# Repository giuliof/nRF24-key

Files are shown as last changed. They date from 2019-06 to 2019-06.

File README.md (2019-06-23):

# nRF key

Interface for Nordic nRF24L01 wireless modules.

## Project structure

In this repository you can find:
```
nRF-key
 |__ schematics --> KiCAD schematic
 |__ code       --> source code for ATtiny2313 microcontroller
```

## BOM

|Designator | Description | MPN |
|---|---|---|
|C2 C7 C8 C10  | capacitor 100n 0805 | 0805F104M500NT |
|C9 | capacitor tantalum 10u | TAJA106K016RNJ |
|C5 C6 | capacitor 22p 0805 | 0805N220J500CT |
|D1 D2 D3 | red led 0805 | QBLP631-R |
|R1 R5 | resistor 10k 0805 | RC0805JR-0710KL |
|R2 R3 R4 | Resistor 330 0805 | 0805W8J0331T5E |
|U2 | microcontroller ATtiny2313 | ATTINY2313A-SU |
|U1 | usb ttl uart ch340c | CH340C |
|U3 | LDO voltage regulator 3v3  | MCP1700T-3302E/TT |
|Y1 | crystal 8M | 1C208000BC0R |

## Code features

Communication with nRF key is via 9600baud 8N1 serial port. Data received from another module is printed. Data to send is packaged in a 32byte maximum structure and must be followed by CR. Bytes over 32 (except for CR) will be ignored.
This is not a transparent bridge, but can be easily implemented.

nRF24L01 registers (i.e. tx/rx addresses) can be reprogrammed pressing programming button (i.e. holding low BTN/PD4 line) while inserting key. Programming mode is selected (both TX_LED and RX_LED will turn on), next 32byte will be stored in settings EEPROM. Data is structured as following:

| Byte n. | Function |  nRF reg. |
|---|---|---|
| 0 |Configure register | 0 |
| 1 |Enable automatic answer function | 1 |
| 2 |Enable receive address | 2 |
| 3 |Setup address width | 3 |
| 4 |Automatic retransmission | 4 |
| 5 |Set channel frequency | 5 |
| 6 |Set transmission rate, LNA gain, transmit power  | 6 |
| 7&div;11|RX address for data channel 0 | 10 |
|12&div;16|RX address for data channel 1 | 11 |
| 17 |RX address for data channel 2 | 12 |
| 18 |RX address for data channel 3 | 13 |
| 19 |RX address for data channel 4 | 14 |
| 20 |RX address for data channel 5 | 15 |
|21&div;25|TX address | 16 |
| 26 |RX data for channel 0 | 17 |
| 27 |RX data for channel 1 | 18 |
| 28 |RX data for channel 2 | 19 |
| 29 |RX data for channel 3 | 20 |
| 30 |RX data for channel 4 | 21 |
| 31 |RX data for channel 5 | 22 |

## How To

1. Make the PCB and solde it (I have a protoboard version too);
2. Obtain an AVR programmer (usbasp or Arduino as ISP)
3. Compile the code:
 * install `gcc-avr` `avr-libc` `avrdude`;
 * move in code directory;
 * type `make`;
 * check in Makefile if the programmer is correct;
 * type `make eeprom` then `make flash`.

## Authors

* **Giulio Fieramosca** - [giuliof](https://github.com/giuliof)

## License

This project is released under the MIT License - see the [LICENSE.md](LICENSE.md) file for details

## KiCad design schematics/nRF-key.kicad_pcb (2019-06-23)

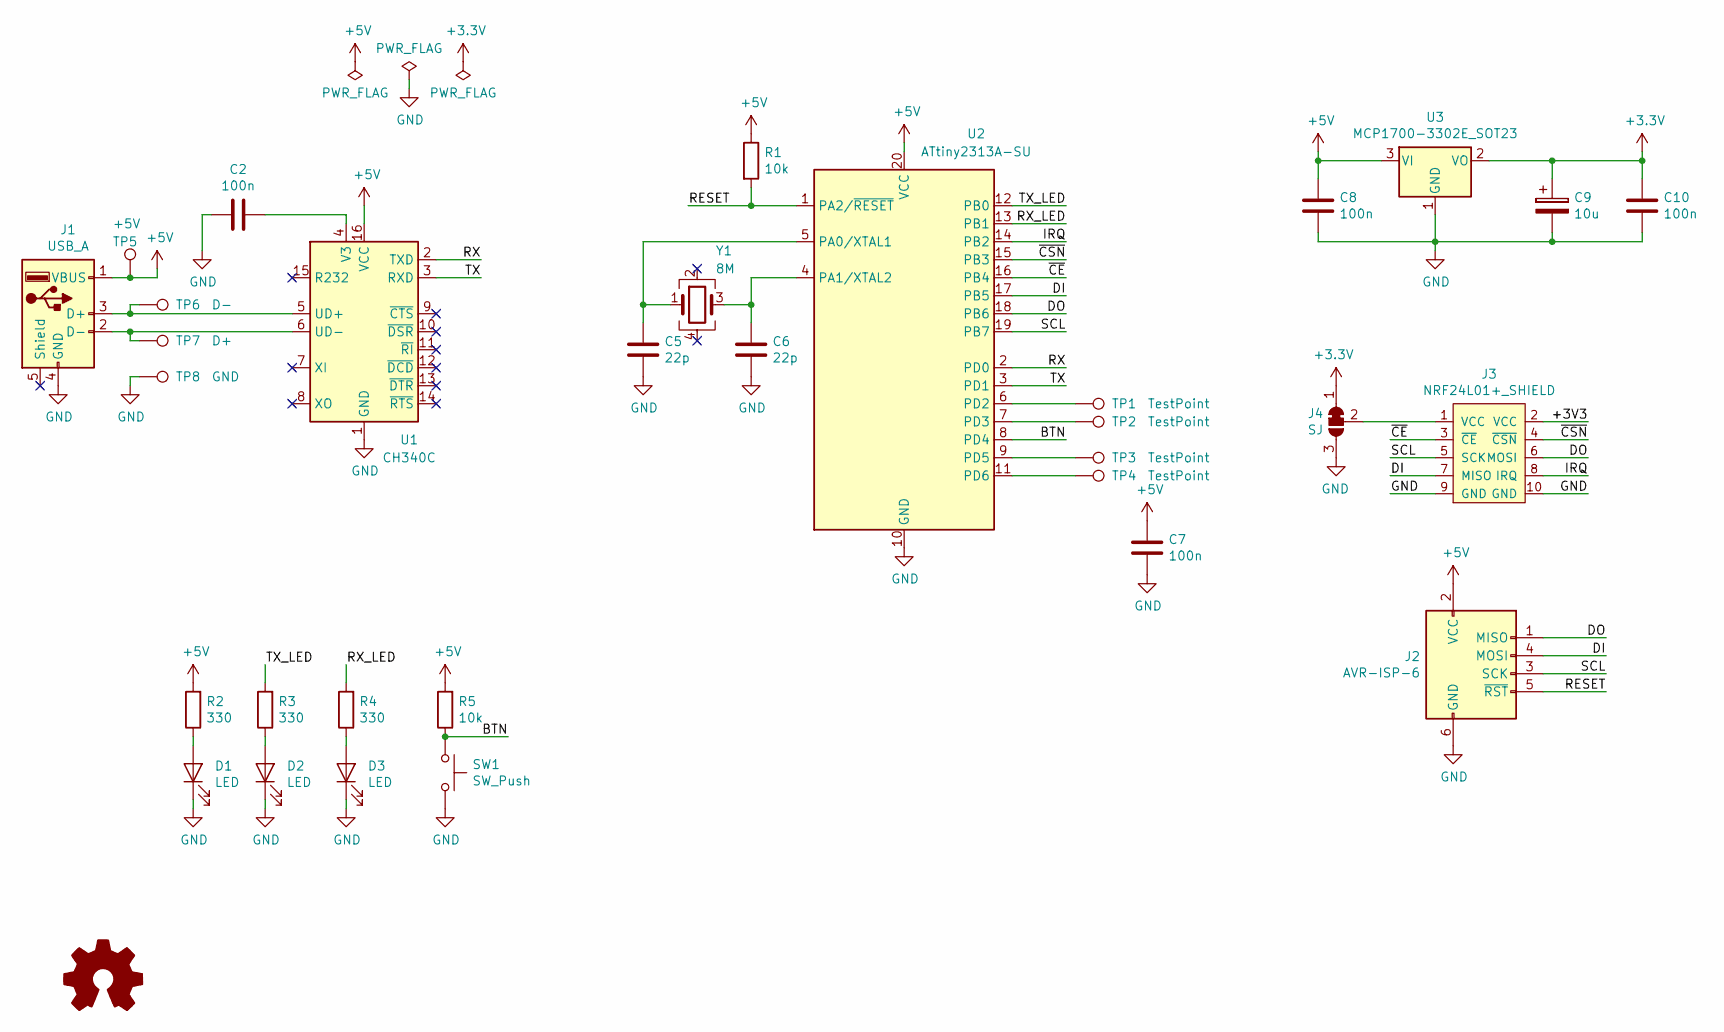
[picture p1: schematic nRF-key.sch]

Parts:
C2, C7, C8, C10: 100n; C_0805_2012Metric; Part no 0805F104M500NT
C5, C6: 22p; C_0805_2012Metric; Part no 0805N220J500CT
C9: 10u; CP_EIA-3216-12_Kemet-S; Part no TAJA106K016RNJ
D1, D2, D3: LED; LED_0805_2012Metric; Part no QBLP631-R
J1: USB_A; usb-PCB
J2: AVR-ISP-6; PogoPins-2x03-ICSP
J3: NRF24L01+_SHIELD; nRF24-2x05_P2.54mm
J4: SJ; SolderJumper-3_P1.3mm_Open_RoundedPad1.0x1.5mm
LOGO1: Logo_Open_Hardware_Small; oshw-logo-10mm
R1, R5: 10k; R_0805_2012Metric; Part no RC0805JR-0710KL
R2, R3, R4: 330; R_0805_2012Metric; Part no 0805W8J0331T5E
SW1: SW_Push; _PTS525SK15-SMT-Pushbutton
TP1, TP2, TP3, TP4: TestPoint; TestPoint_THTPad_D1.0mm_Drill0.5mm
TP5: +5V; TestPoint_THTPad_D1.0mm_Drill0.5mm
TP6: D-; TestPoint_THTPad_D1.0mm_Drill0.5mm
TP7: D+; TestPoint_THTPad_D1.0mm_Drill0.5mm
TP8: GND; TestPoint_THTPad_D1.0mm_Drill0.5mm
U1: CH340C; SOIC-16_3.9x9.9mm_P1.27mm; Part no CH340C
U2: ATtiny2313A-SU; SOIC-20W_7.5x12.8mm_P1.27mm; Part no ATTINY2313A-SU
U3: MCP1700-3302E_SOT23; SOT-23; Part no MCP1700T-3302E/TT
Y1: 8M; Crystal_SMD_3225-4Pin_3.2x2.5mm; Part no 1C208000BC0R

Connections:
+5V: C7.1, C8.1, J1.1 (VBUS), J2.2 (VCC), R1.1, R2.2, R5.2, TP5.1, U1.16 (VCC), U2.20 (VCC), U3.3 (VI)
/BTN: R5.1, SW1.1, U2.8 (PD4)
/DI: J2.4 (MOSI), J3.7 (MISO), U2.17 (PB5)
/DO: J2.1 (MISO), J3.6 (MOSI), U2.18 (PB6)
/IRQ: J3.8 (IRQ), U2.14 (PB2)
/RESET: J2.5 (~RST), R1.2, U2.1 (PA2/~RESET)
/RX: U1.2 (TXD), U2.2 (PD0)
/RX_LED: R4.2, U2.13 (PB1)
/SCL: J2.3 (SCK), J3.5 (SCK), U2.19 (PB7)
/TX: U1.3 (RXD), U2.3 (PD1)
/TX_LED: R3.2, U2.12 (PB0)
/~CE~: J3.3 (~CE~), U2.16 (PB4)
/~CSN~: J3.4 (~CSN~), U2.15 (PB3)
GND: C2.2, C5.2, C6.2, C7.2, C8.2, C9.2, C10.2, D1.1 (K), D2.1 (K), D3.1 (K), J1.4 (GND), J2.6 (GND), J3.9 (GND), J3.10 (GND), J4.3 (B), SW1.2, TP8.1, U1.1 (GND), U2.10 (GND), U3.1 (GND)
unnamed: C2.1, U1.4 (V3)
unnamed: C5.1, U2.5 (PA0/XTAL1), Y1.1
unnamed: C6.1, U2.4 (PA1/XTAL2), Y1.3
unnamed: D1.2 (A), R2.1
unnamed: D2.2 (A), R3.1
unnamed: D3.2 (A), R4.1
unnamed: J1.2 (D-), TP7.1, U1.6 (UD-)
unnamed: J1.3 (D+), TP6.1, U1.5 (UD+)
unnamed: J3.1 (VCC), J4.2 (C)
unnamed: TP1.1, U2.6 (PD2)
unnamed: TP2.1, U2.7 (PD3)
unnamed: TP3.1, U2.9 (PD5)
unnamed: TP4.1, U2.11 (PD6)

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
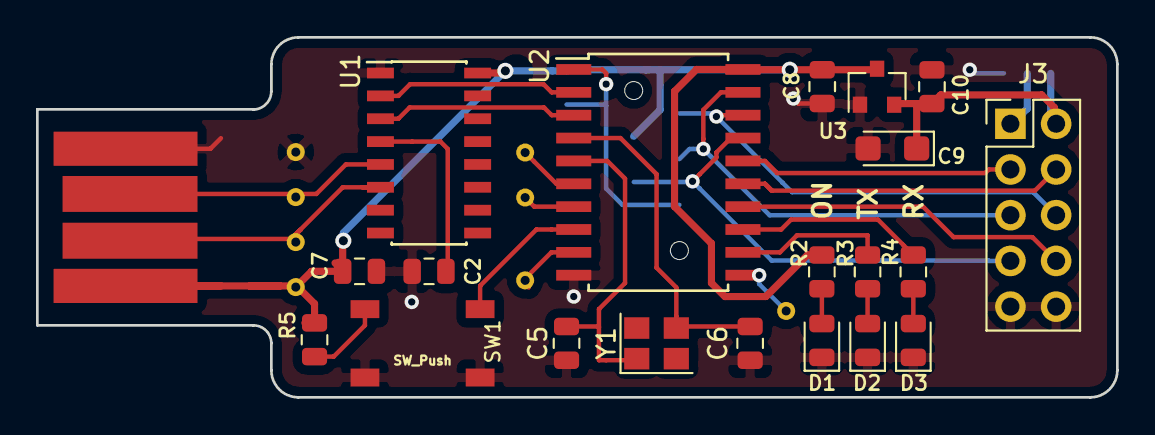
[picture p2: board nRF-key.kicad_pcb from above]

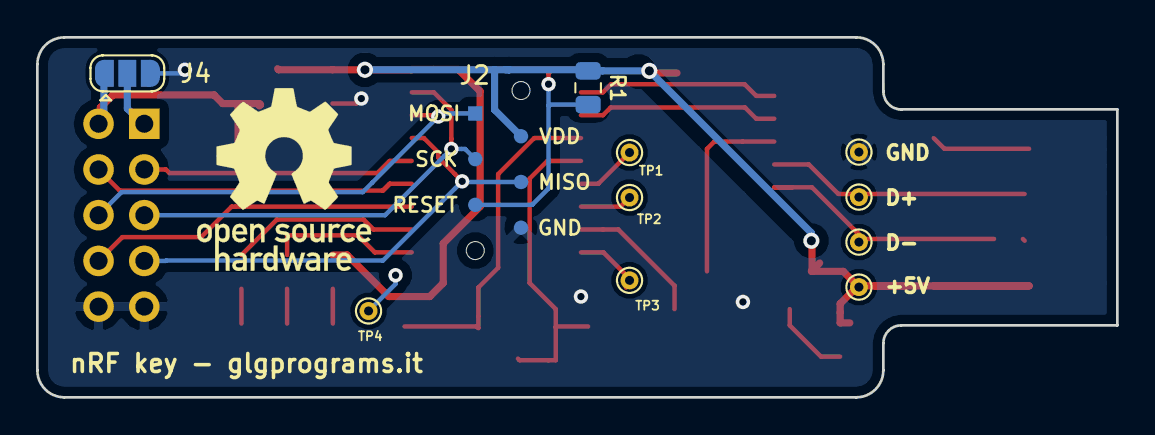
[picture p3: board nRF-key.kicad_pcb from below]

Board: 2 copper layers, 60.0 x 20.0 mm, 33 parts (12 on the bottom side), 28 nets.

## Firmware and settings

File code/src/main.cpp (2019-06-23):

#include "GPIO.h"
#include "UART.h"
#include "nRF24L01.h"
#include "utils.h"
#include <avr/io.h>
#include <avr/pgmspace.h>
#include <util/delay.h>

static char dataBuffer_rx[RX_PLOAD_WIDTH];
static char dataBuffer[TX_PLOAD_WIDTH];
static uint8_t dataCnt = 0;

int main() {
  _delay_ms(100);

  UART_init();

  NRF24L01_Init();

  GPIO_init();

  while (NRF24L01_Check()) {
    UART_send(error);
    _delay_ms(500);
  }

  // Enter in programming mode
  if (!(PIND & _BV(4))) {
    TXLED_ON();
    RXLED_ON();
    NRF24L01_UpdateCfg();
    TXLED_OFF();
    RXLED_OFF();
  }

  NRF24L01_SetUp();

  while (1) {
    char ch;

    // Check if someone is writing on serial
    if (UART_RXC()) {
      // Check if buffer overflow
      if (UART_OF()) {
        for (uint8_t i = 0; i < dataCnt; i++)
          dataBuffer[i] = 0;
        dataCnt = 0;

        // Flush corrupted buffer
        while (UART_RXC())
          ch = UDR;
      } else {
        ch = UDR;

        if (ch == '\r') {
          if (dataCnt == 0) {
            NRF24L01_DumpCfg();
            continue;
          }
          // Turn on TX LED
          TXLED_ON();

          // Temporary set as TX
          NRF24L01_TX_Mode();

          // Send all data
          if (NRF24L01_TxPacket((uint8_t *)dataBuffer) != TX_OK)
            UART_send(error);
          else
            UART_send(success);

          // Fallback to RX
          NRF24L01_RX_Mode();

          for (uint8_t c = 0; c < dataCnt; c++) {
            while (!UART_DRE())
              ;

            UDR = dataBuffer[c];

            dataBuffer[c] = 0;
          }

          dataCnt = 0;

          // Turn off TX LED
          TXLED_OFF();
        } else if (dataCnt < TX_PLOAD_WIDTH) {
          dataBuffer[dataCnt++] = ch;
        }
      }
    }

    // Check if incoming data on nRF is present
    if (NRF24L01_RxPacket((uint8_t *)dataBuffer_rx) == 0) {
      RXLED_ON();

      UART_send(dataBuffer_rx, RX_PLOAD_WIDTH);

      RXLED_OFF();
    }
  }
}

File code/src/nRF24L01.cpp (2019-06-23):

#include <avr/io.h>
#include <util/delay.h>
#include <avr/eeprom.h>
#include "nRF24L01.h"
#include "UART.h"

static void SPI_Init() {
  // Set DO and SCL as output with pullups
  DDRB |= _BV(PB6);  // as output (DO) - data out
  DDRB |= _BV(PB7);  // as output (USISCK) - clock
  DDRB &= ~_BV(PB5); // as input (DI) - data in
  PORTB |= _BV(PB5); // pullup on (DI)

  DDR(PIN_SPI_CS) |= _BV(PIN(PIN_SPI_CS));

  SPI_CS_HIGH();
}

static uint8_t SPI_ReadWriteByte(uint8_t dat) {
  USIDR = dat;

  // Clear Overflow Interrupt Flag
  USISR = _BV(USIOIF);

  // Do this loop 16times
  do {
    // Send clock pulse
    USICR |= _BV(USITC) | _BV(USIWM0) | _BV(USICS1) | _BV(USICLK);
    // 100kHz SPI
    _delay_us(5);
  } while (!(USISR & _BV(USIOIF)));

  return USIDR;
}


/* NRF24L01_Read_Reg: read an nRF register content
 * reg: register address
 * Return value: register's content
 */
static uint8_t NRF24L01_Read_Reg(uint8_t reg) {
  uint8_t reg_val;

  SPI_CS_LOW();
  SPI_ReadWriteByte(reg);
  reg_val = SPI_ReadWriteByte(0XFF);
  SPI_CS_HIGH();

  return reg_val;
}

/* NRF24L01_Write_Reg: write an nRF register
 * reg: register address
 * value: register value
 * Return value: status
 */
static uint8_t NRF24L01_Write_Reg(uint8_t reg, uint8_t value) {
  uint8_t status;

  SPI_CS_LOW();
  status = SPI_ReadWriteByte(reg);
  SPI_ReadWriteByte(value);
  SPI_CS_HIGH();

  return status;
}

/* NRF24L01_Read_Buf: read specified data length at specified nRF address
 * reg:  nRF register location
 * pBuf: data buffer
 * len:  data length
 * return value: status register value
 */
static uint8_t NRF24L01_Read_Buf(uint8_t reg, uint8_t *pBuf, uint8_t len) {
  uint8_t status;

  SPI_CS_LOW();
  status = SPI_ReadWriteByte(reg);
  for (uint8_t c = 0; c < len; c++)
    pBuf[c] = SPI_ReadWriteByte(0xFF); // gibberish data
  SPI_CS_HIGH();

  return status;
}

/* NRF24L01_Write_Buf: write data buffer to certain nRF address
 * reg:  nRF register location
 * pBuf: data buffer
 * len:  data length
 * return value: status register value
 */
static uint8_t NRF24L01_Write_Buf(uint8_t reg, uint8_t *pBuf, uint8_t len) {
  uint8_t status;

  SPI_CS_LOW();
  _delay_us(5);
  status = SPI_ReadWriteByte(reg);
  for (uint8_t c = 0; c < len; c++) {
    SPI_ReadWriteByte(*pBuf++);
  }
  _delay_us(5);
  SPI_CS_HIGH();

  return status;
}


// NRF24L01 initialisation
void NRF24L01_Init() {
  DDR(PIN_24L01_CE) |= _BV(PIN(PIN_24L01_CE));
  DDR(PIN_24L01_IRQ) &= ~_BV(PIN(PIN_24L01_IRQ));
  OUT(PIN_24L01_IRQ) |= _BV(PIN(PIN_24L01_IRQ));

  SPI_Init();

  NRF24L01_CE_LOW();
  SPI_CS_HIGH();
}

// Check presence of nRF24 module
uint8_t NRF24L01_Check() {
  uint8_t buf[5] = {0xA5, 0xA5, 0xA5, 0xA5, 0xA5};
  uint8_t i;

  NRF24L01_Write_Buf(NRF_WRITE_REG + TX_ADDR, buf, 5);
  NRF24L01_Read_Buf(TX_ADDR, buf, 5);
  for (i = 0; i < 5; i++)
    if (buf[i] != 0xA5)
      break;
  if (i != 5)
    return 1;
  return 0;
}

void NRF24L01_SetUp() {
  // Data buffer containing setting read from EEPROM
	uint8_t eebuffer[7];

  NRF24L01_CE_LOW();

  eeprom_read_block(eebuffer, (const void*)0, 7);
  for (uint8_t i = 0; i < 7; i++)
    NRF24L01_Write_Reg(NRF_WRITE_REG + CONFIG + i, eebuffer[i]); // Enable CRC, 16-bit wide
  
  // Set RX address 0
	eeprom_read_block(eebuffer, (const void*)7, RX_ADR_WIDTH);
  //UART_sendHex(eebuffer, 5);
  NRF24L01_Write_Buf(NRF_WRITE_REG + RX_ADDR_P0, eebuffer, RX_ADR_WIDTH);
  // Set RX address 1
	eeprom_read_block(eebuffer, (const void*)12, RX_ADR_WIDTH);
  //UART_sendHex(eebuffer, 5);
  NRF24L01_Write_Buf(NRF_WRITE_REG + RX_ADDR_P1, eebuffer, RX_ADR_WIDTH);
  // Set RX address 2-5
  eeprom_read_block(eebuffer, (const void*)17, 4);
  //UART_sendHex(eebuffer, 4);
  for (uint8_t i = 0; i < 4; i++)
    NRF24L01_Write_Reg(NRF_WRITE_REG + RX_ADDR_P2 + i, eebuffer[i]);

	// Set TX address
	eeprom_read_block(eebuffer, (const void*)21, TX_ADR_WIDTH);
  //UART_sendHex(eebuffer, 5);
  NRF24L01_Write_Buf(NRF_WRITE_REG + TX_ADDR, eebuffer, TX_ADR_WIDTH);

  // Set RX_ADDR_P*
  eeprom_read_block(eebuffer, (const void*)26, 6);
  //UART_sendHex(eebuffer, 6);
  for (uint8_t i = 0; i < 6; i++)
    NRF24L01_Write_Reg(NRF_WRITE_REG + RX_PW_P0 + i, eebuffer[i]);
  
  NRF24L01_CE_HIGH();
}

/* NRF24L01_TxPacket: send data packet with nRF24
 * txbuf: address of first byte to send
 * Return value: send completion status
 */
uint8_t NRF24L01_TxPacket(uint8_t *txbuf) {
  uint8_t status;

  NRF24L01_CE_LOW();
  NRF24L01_Write_Buf(WR_TX_PLOAD, txbuf, TX_PLOAD_WIDTH);
  NRF24L01_CE_HIGH();

  while (NRF24L01_IRQ() != 0)
    ;

  status = NRF24L01_Read_Reg(STATUS);
  NRF24L01_Write_Reg(NRF_WRITE_REG + STATUS, status);

  // Maximum number of retransmission reached
  if (status & MAX_TX) {
    NRF24L01_Write_Reg(FLUSH_TX, 0xff);
    return MAX_TX;
  }

  if (status & TX_OK)
    return TX_OK;

  return 0xff;
}

/* NRF24L01_RxPacket: receive data packet with nRF24
 * rxbuf: address of first byte of receive data buffer
 * Return value: 0 if success, 1 if no data present
 */
uint8_t NRF24L01_RxPacket(uint8_t *rxbuf) {
  uint8_t status;

  status = NRF24L01_Read_Reg(STATUS);
  NRF24L01_Write_Reg(NRF_WRITE_REG + STATUS, status);
  if (status & RX_OK) {
    NRF24L01_Read_Buf(RD_RX_PLOAD, rxbuf, RX_PLOAD_WIDTH);
    NRF24L01_Write_Reg(FLUSH_RX, 0xff);
    return 0;
  }
  return 1;
}

void NRF24L01_RX_Mode() {
  uint8_t cfg;
  cfg = NRF24L01_Read_Reg(NRF_READ_REG + CONFIG);
  NRF24L01_CE_LOW();
  NRF24L01_Write_Reg(NRF_WRITE_REG + CONFIG, cfg | _BV(0));
  NRF24L01_CE_HIGH();
}

void NRF24L01_TX_Mode() {
  uint8_t cfg;
  cfg = NRF24L01_Read_Reg(NRF_READ_REG + CONFIG);
  NRF24L01_CE_LOW();
  NRF24L01_Write_Reg(NRF_WRITE_REG + CONFIG, cfg & ~_BV(0));
  NRF24L01_CE_HIGH();
}

void NRF24L01_DumpCfg() {
  uint8_t eebuffer[7];

  for (uint8_t i = 0; i < 7; i++)
   eebuffer[i] = NRF24L01_Read_Reg(NRF_READ_REG + CONFIG + i); // Enable CRC, 16-bit wide
  UART_sendHex(eebuffer, 7);

  NRF24L01_Read_Buf(NRF_READ_REG + RX_ADDR_P0, eebuffer, RX_ADR_WIDTH);
  UART_sendHex(eebuffer, 5);

  NRF24L01_Read_Buf(NRF_READ_REG + RX_ADDR_P1, eebuffer, RX_ADR_WIDTH);
  UART_sendHex(eebuffer, 5);

  for (uint8_t i = 0; i < 4; i++)
    eebuffer[i] = NRF24L01_Read_Reg(NRF_READ_REG + RX_ADDR_P2 + i);
  UART_sendHex(eebuffer, 4);


  NRF24L01_Read_Buf(NRF_READ_REG + TX_ADDR, eebuffer, TX_ADR_WIDTH);
  UART_sendHex(eebuffer, 5);

  for (uint8_t i = 0; i < 6; i++)
    eebuffer[i] = NRF24L01_Read_Reg(NRF_READ_REG + RX_PW_P0 + i);
  UART_sendHex(eebuffer, 6);
}

void NRF24L01_UpdateCfg() {
  // flush previous data
  while (UART_RXC())
    uint8_t tmp = UDR;

  for (uint8_t* i = 0; i < (const uint8_t*)32; i++) {
    uint8_t data;
    // send ready to receive
    UDR = (int)i;

    // wait for data
    while (!UART_RXC())
      ;
    
    data = UDR;  
    eeprom_update_byte(i, data);
  }
}
